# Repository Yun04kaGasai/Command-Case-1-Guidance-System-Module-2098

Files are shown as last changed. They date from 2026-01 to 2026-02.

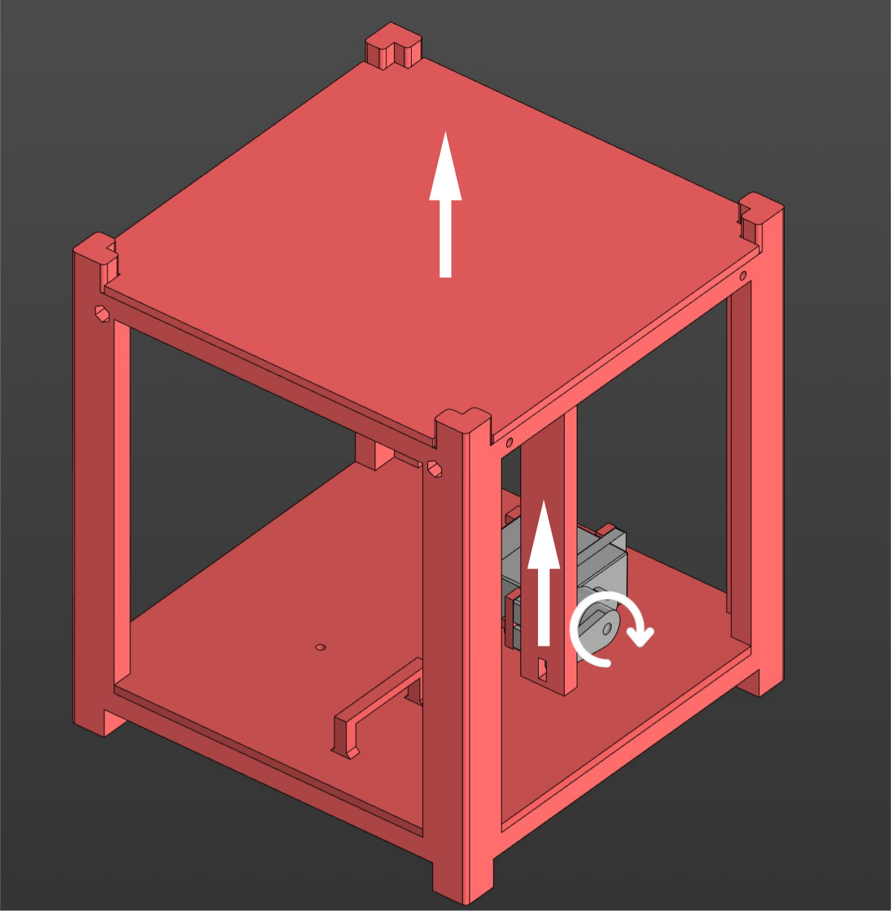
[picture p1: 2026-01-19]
Assets/Kinematicheskaya skhema 2.png

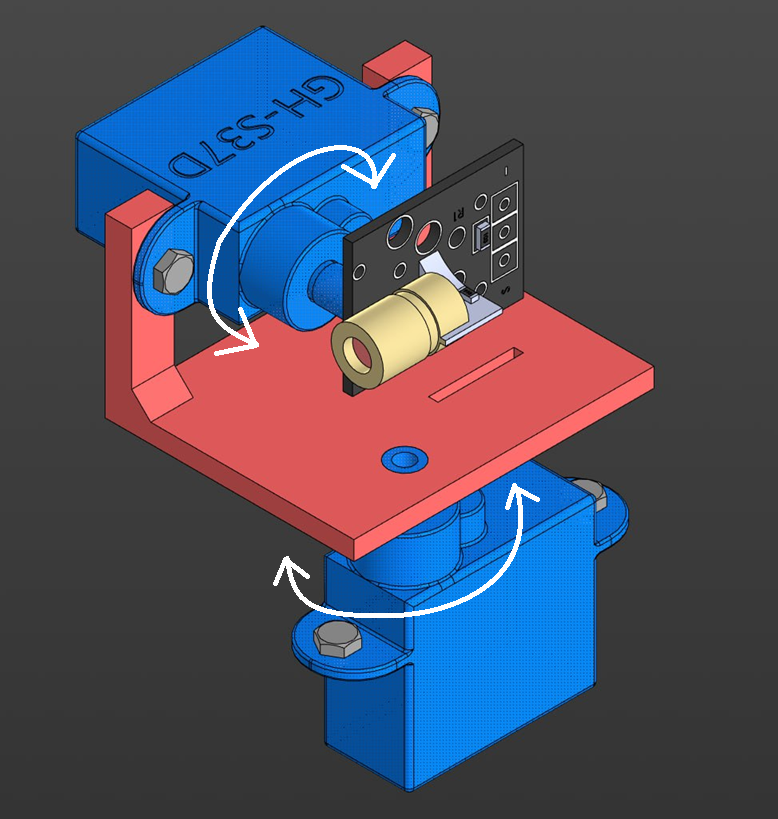
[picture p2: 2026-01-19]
Assets/Kinematicheskaya skhema 1.png

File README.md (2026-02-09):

# Описание модуля
isometry isometry razn

## Модуль обеспечивает:
- Двухосевое наведение лазерного луча (±40° по каждой оси с шагом 10°), исходящего из геометрического центра корпуса CubeSat 1U;
- Приём управляющих команд по радиоканалу (nRF24L01);
- Последовательное выполнение четырёх тестовых сканирующих режимов: горизонтального, вертикального и двух диагональных;
- Автономную работу исполнительной части сразу после включения питания;
- Отправку телеметрической информации — включая уникальный ID устройства, текущие углы наведения и номер активного режима.
## Аппаратная часть включает:
- STM32 Blue Pill — главный контроллер (наземная станция), принимающий команду START от ПК и передающий последовательности позиций по радио;
- Raspberry Pi Pico (RP2040) — исполнительный модуль внутри CubeSat, управляющий двумя сервоприводами GH-S37A и лазером KY-008;
- Радиомодуль nRF24L01 для односторонней связи от STM32 к RP2040;
- Собственный 3D-напечатанный корпус, соответствующий стандарту CubeSat 1U, с учётом размещения лазера в геометрическом центре.
### Проект полностью реализован участниками: от проектирования механики и электронной схемы до разработки прошивки обеих микроконтроллеров и сборки макета.

# Руководители
- Пивоварова Наталья Викторовна
- Гоптарь Евгений Андреевич
# Участники команды:
- Хачатрян Карен 11Г Школа №2098
- Козадаев Егор 11Г Школа №2098
- Зотова София 11Г Школа №2098
- Лукашев Николай 11Г Школа №2098
# Этапы производства
- Проектирование:
    - Создание алгоритма
    - Создание 3д моделей и параллельная разработка электронной схемы
- Создание документации и параллельное прототипирование
- Сборка и написание кода
- Испытание (Финал)
## Цель такова:
#### Реализовать решение задания по созданию спутника формата Cubesat 1U, сделав ему оптимальную компановку и разработав корпус с надёжным креплением, который будет укладываться в размерные стандарты таковых.

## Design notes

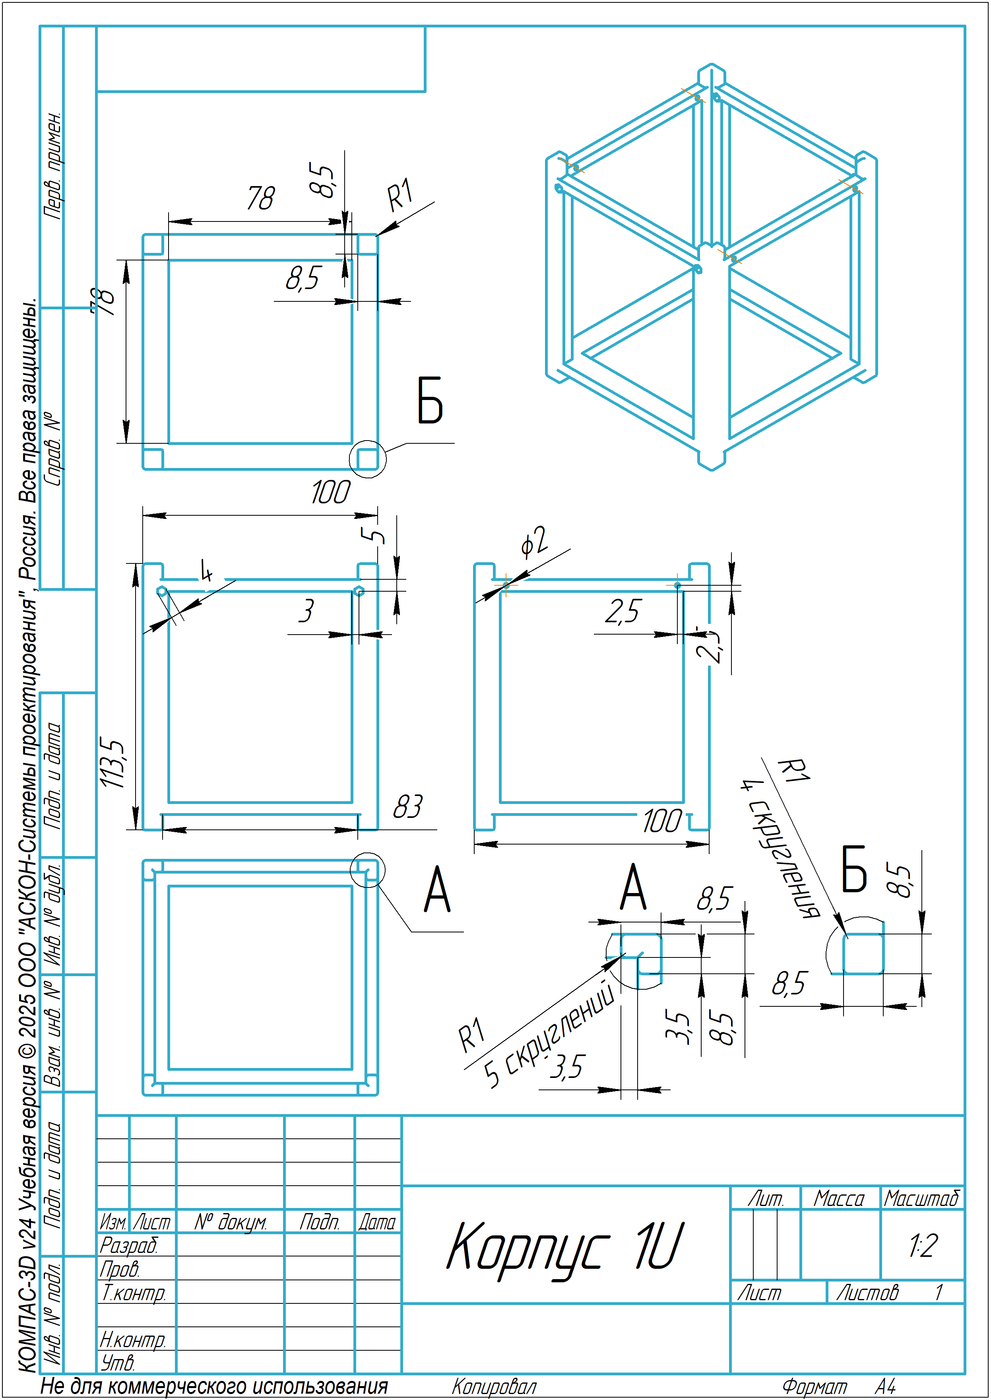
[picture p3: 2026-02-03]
Assets/Чертежи/Корпус 1U.png

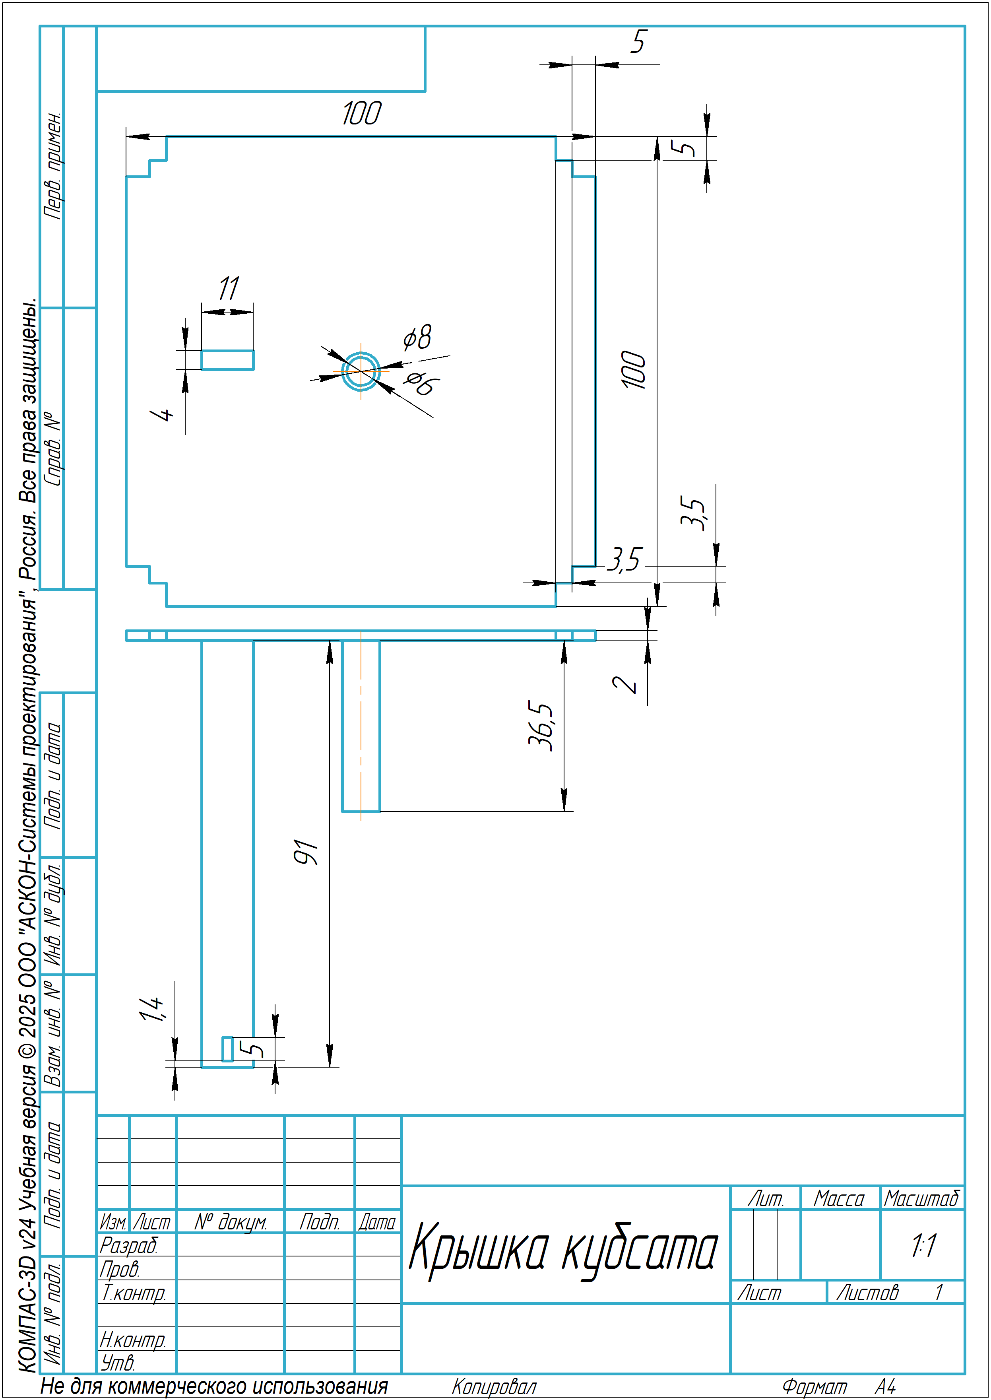
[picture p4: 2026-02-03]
Assets/Чертежи/Крышка кубсата.png

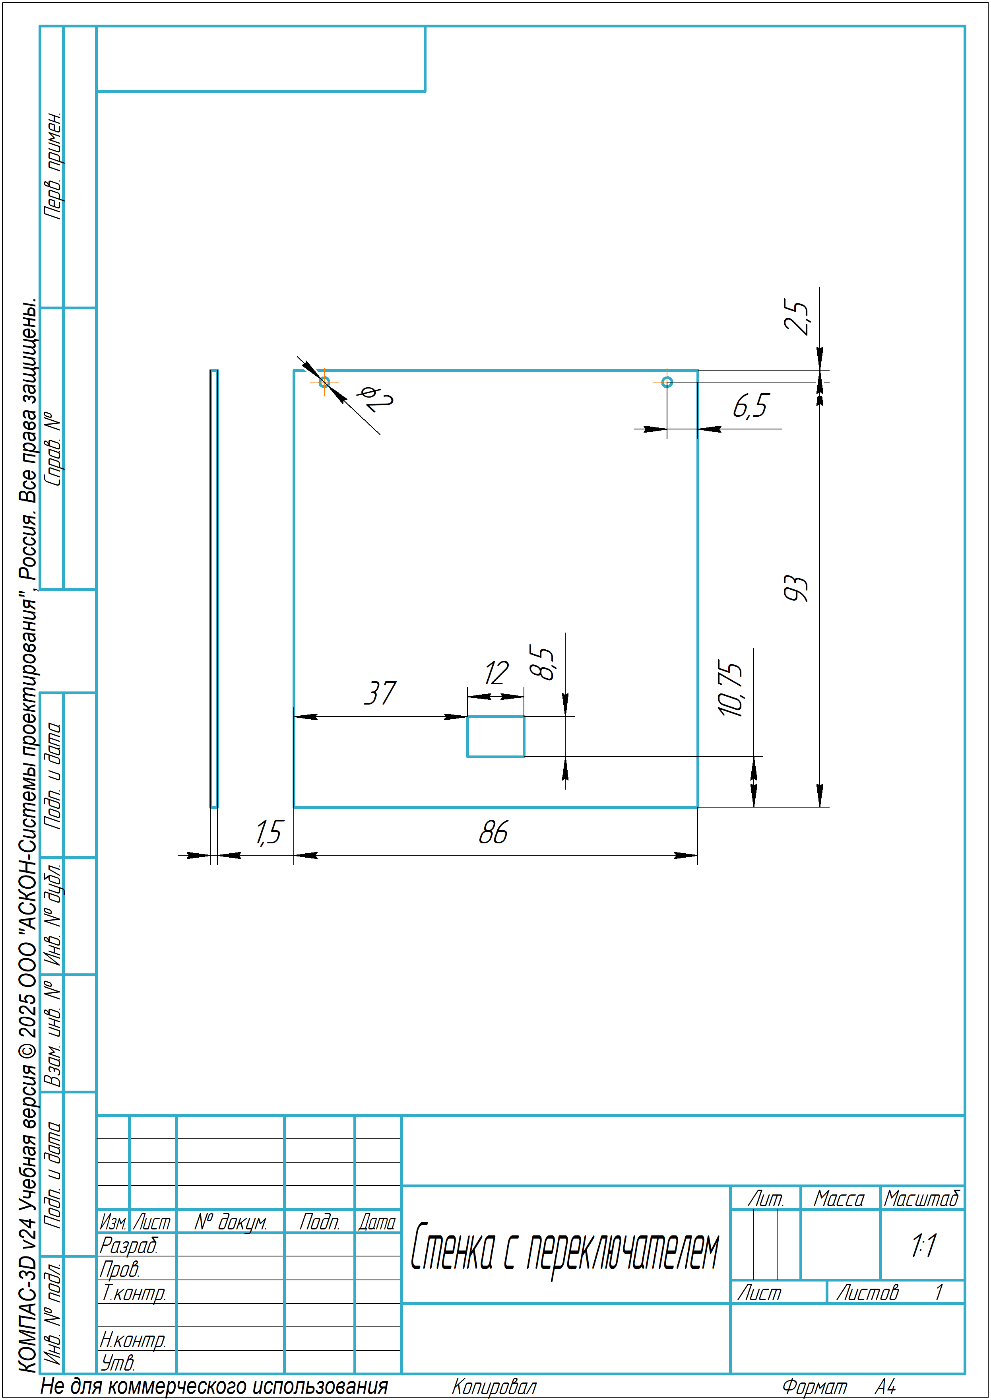
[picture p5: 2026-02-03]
Assets/Чертежи/Стенка с переключателем.png

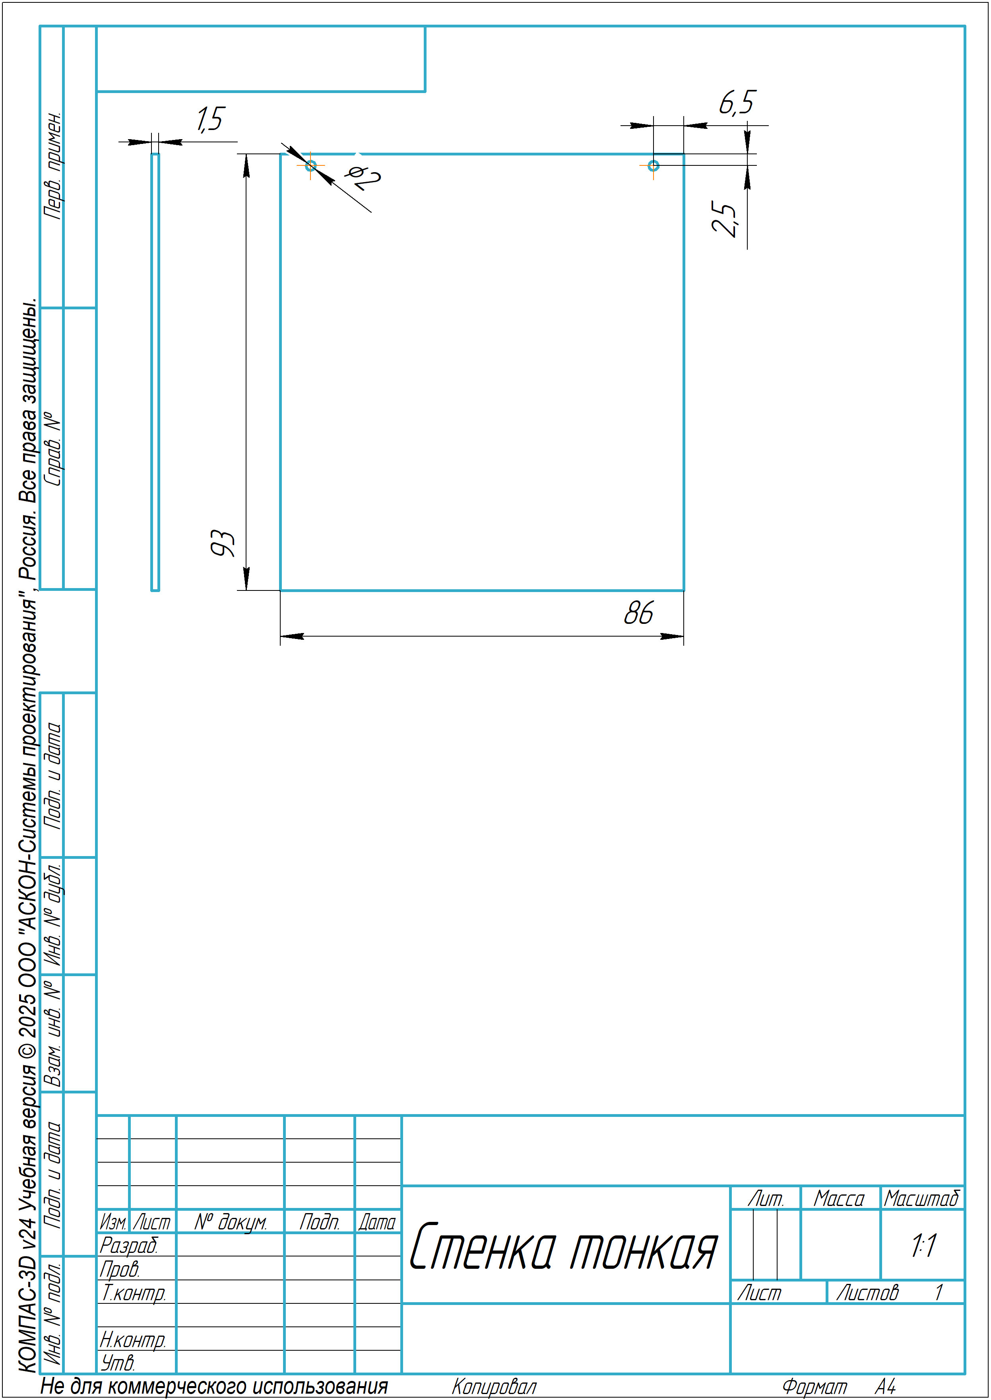
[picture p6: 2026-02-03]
Assets/Чертежи/Стенка тонкая.png

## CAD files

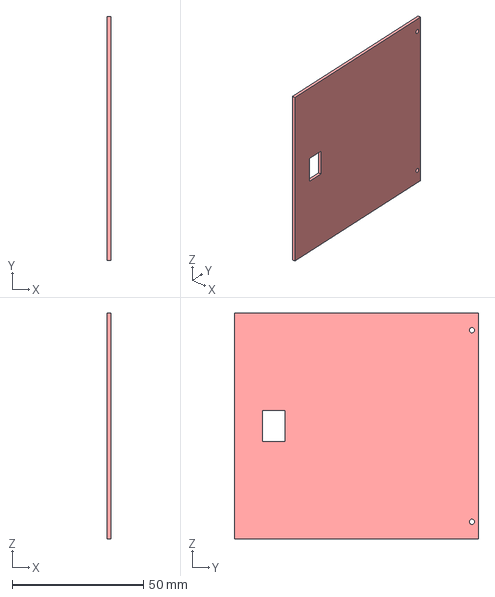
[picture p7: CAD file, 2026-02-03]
3D-модели/Стенка с переключателем.stp
1.50 x 93.0 x 86.0 mm

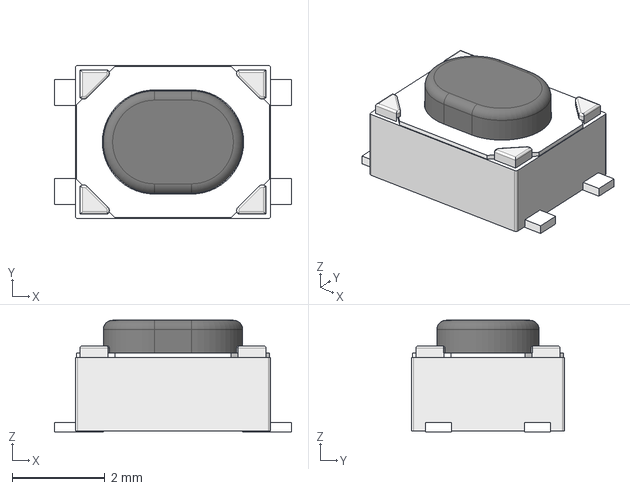
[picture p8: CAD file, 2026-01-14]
Assets/Сборка/RP2040/KLS7-TS3401_B.stp
5.10 x 3.30 x 2.40 mm

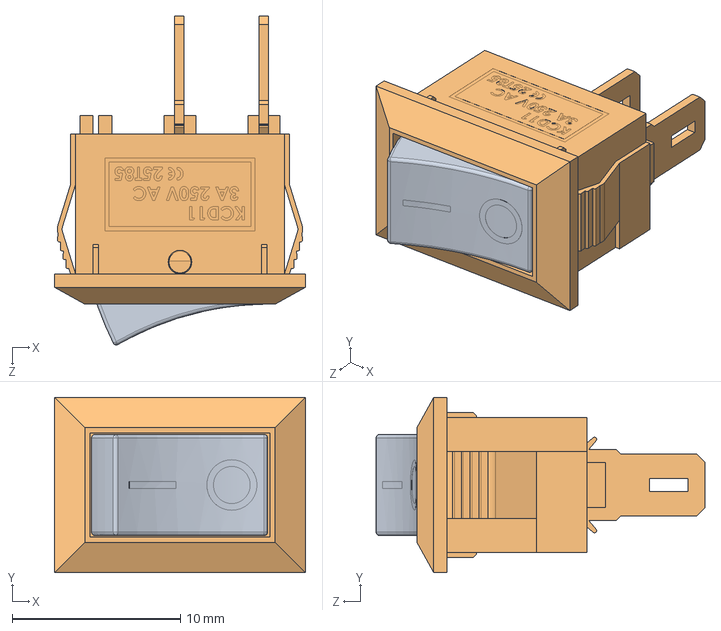
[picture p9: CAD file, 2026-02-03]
Assets/Сборка/Switch_KCD11.STEP
14.9 x 10.4 x 19.5 mm

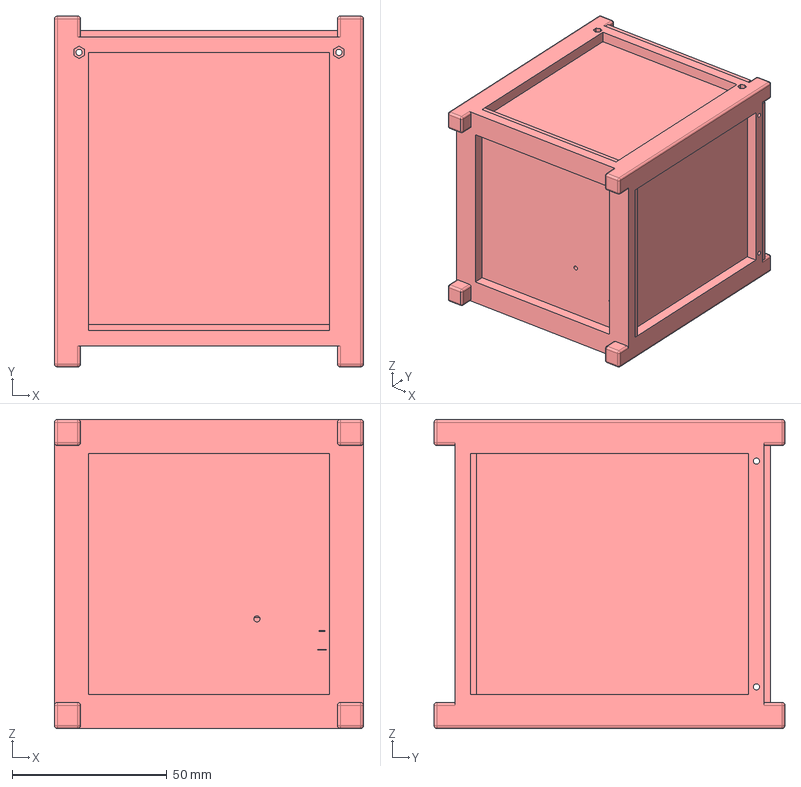
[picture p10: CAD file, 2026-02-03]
3D-модели/Сборка Кубсат.stp
100.0 x 113.5 x 100.0 mm
Gh-S37D Servo x 2
KY-008
AMS1117Pin
Text x 2
AMS1117Body x 2
AMS117Pin
LEDS_3
C-Type Female - 6-Pin SMD
0603 Chip SMD LED (1.6x0.8mm) x 4
Nrf24L01
MG90S
arm

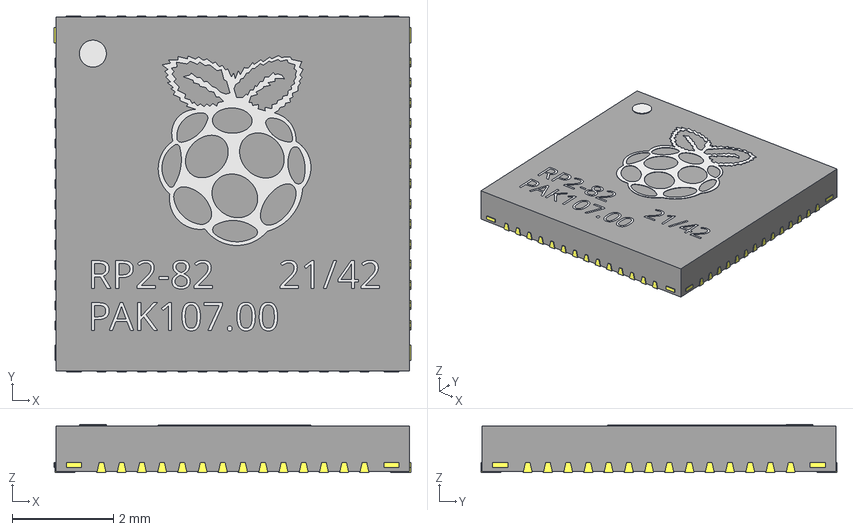
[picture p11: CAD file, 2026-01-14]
Assets/Сборка/RP2040/IC_RP2040.step
7.05 x 7.04 x 0.95 mm
Metal
Pin001
Pin002
Pin003
Pin004
Pin005
Pin006
Pin007
Pin008
Pin009
Pin010
Pin011
Pin012
Pin013
Pin014
Pin015
Pin016
Pin017
Pin018
Pin019
Pin020
Pin021
Pin022
Pin023
Pin024
Pin025
Pin026
Pin027
Pin028
Pin029
Pin030
Pin031
Pin032
Pin033
Pin034
Pin035
Pin036
Pin037
Pin038
Pin039
Pin040
Pin041
Pin042
Pin043
Pin044
Pin045
Pin046
Pin047
Pin048
Pin049
Pin050
Pin051
Pin052
Pin053
Pin054
Pin055
Pin056
ShapeString003
ShapeString002
ShapeString001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

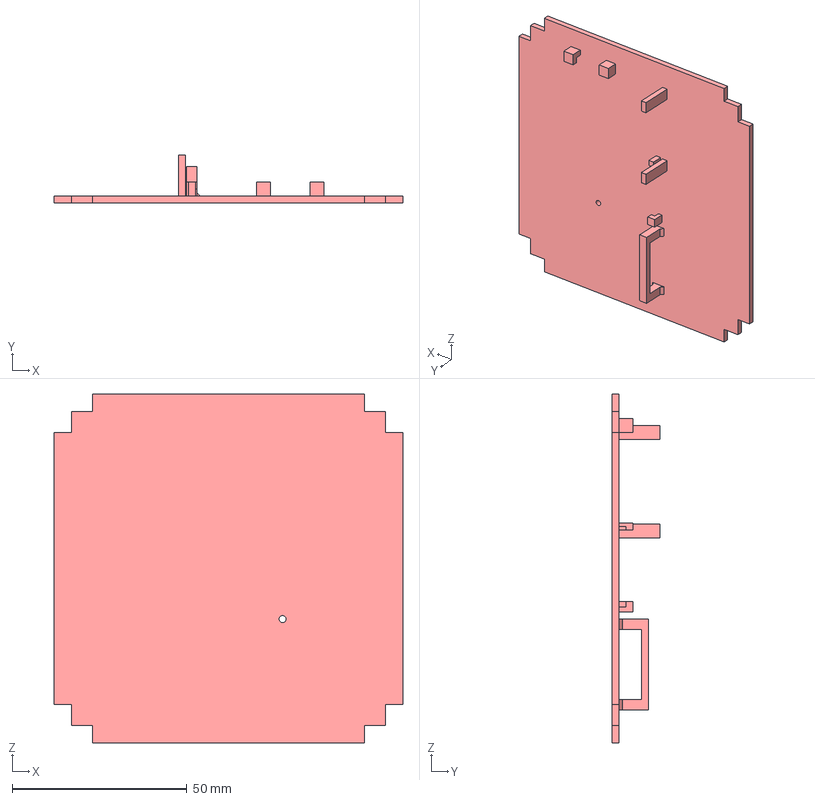
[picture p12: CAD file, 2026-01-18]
Assets/Сборка/Дно.stp
100.0 x 13.8 x 100.0 mm

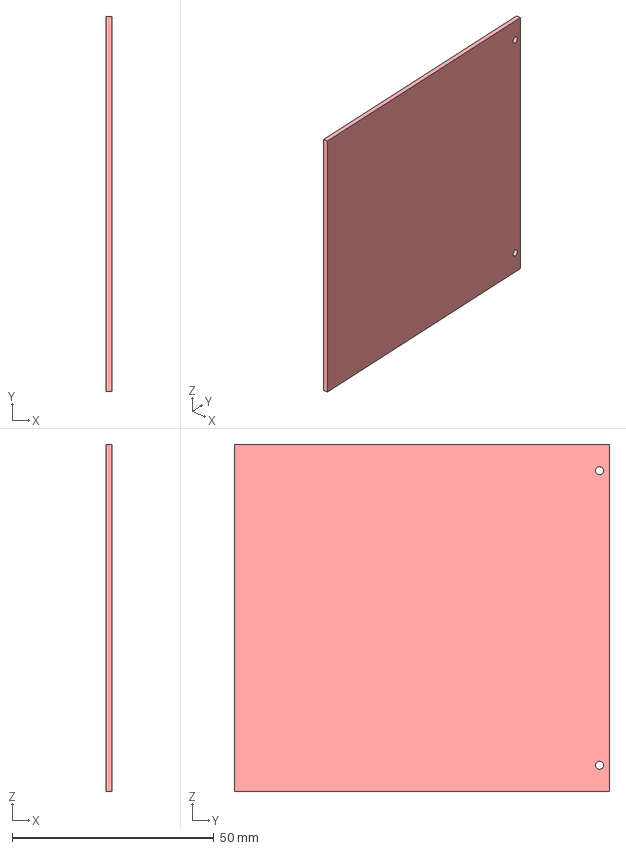
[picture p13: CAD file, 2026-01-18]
3D-модели/Стенка малая.stp
1.50 x 93.0 x 86.0 mm

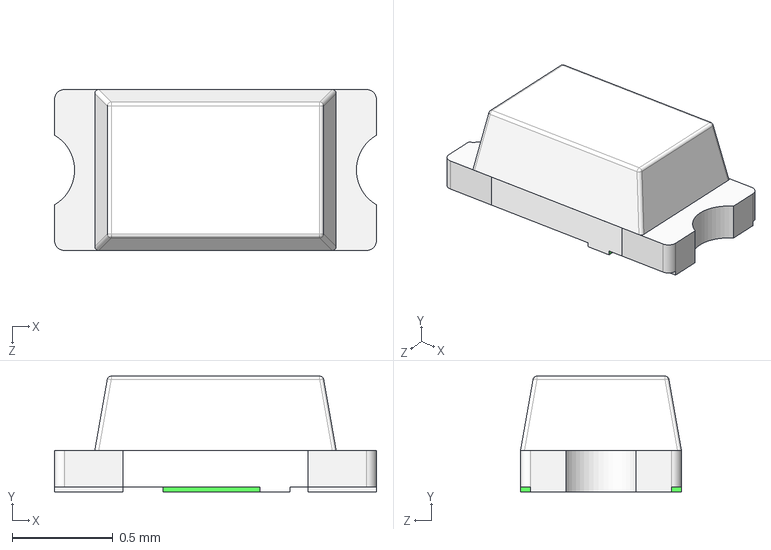
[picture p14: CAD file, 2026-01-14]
Assets/Сборка/RP2040/0603 Chip SMD LED (1.6x0.8mm).STEP
1.60 x 0.575 x 0.8 mm

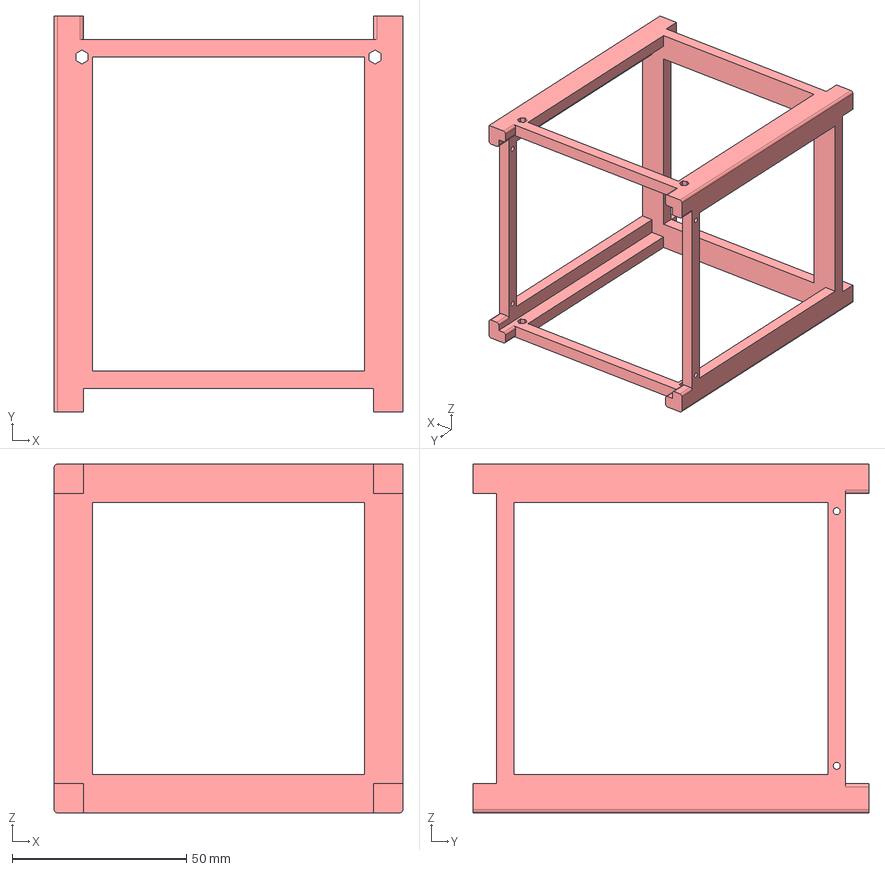
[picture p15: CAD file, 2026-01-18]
Assets/Сборка/Корпус.stp
100.0 x 113.5 x 100.0 mm

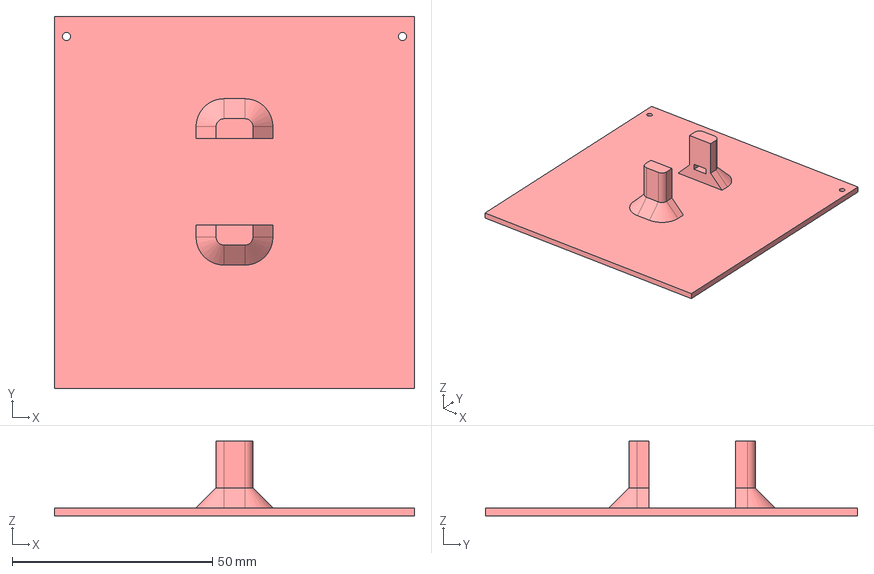
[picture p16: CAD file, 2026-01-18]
3D-модели/Стенка_С_Креплением.stp
90.0 x 93.0 x 18.7 mm

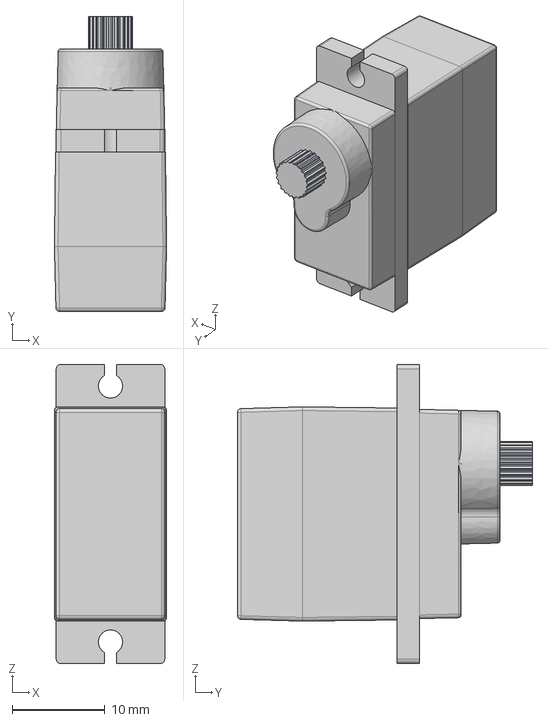
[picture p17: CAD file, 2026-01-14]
Assets/Сборка/MG90S TEETH.step
12.1 x 31.8 x 32.2 mm

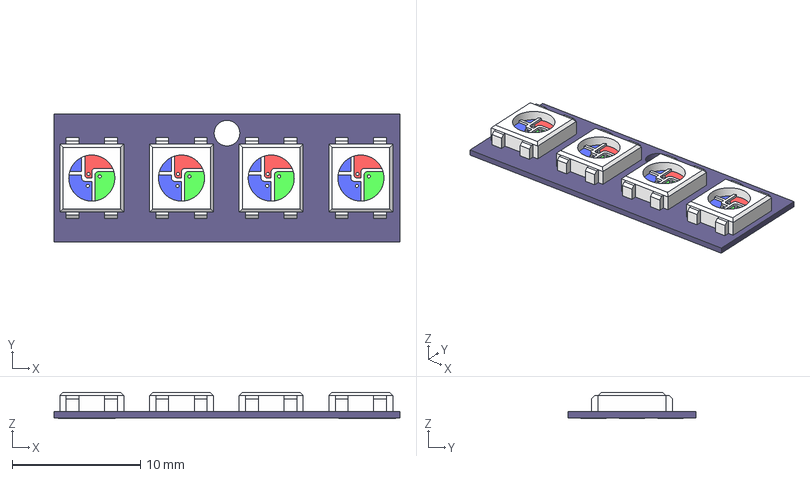
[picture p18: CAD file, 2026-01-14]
Assets/Сборка/RP2040/WS2812-4 ICQMCU.step
27.0 x 10.0 x 2.05 mm
Sketch
PCB
LEDS
Solder strips

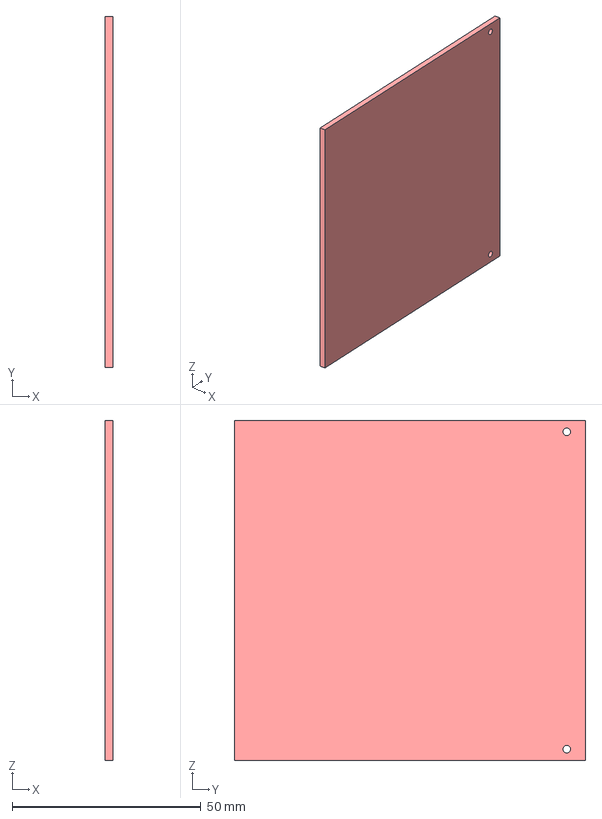
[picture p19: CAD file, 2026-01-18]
3D-модели/Стенка большая.stp
2.00 x 93.0 x 90.0 mm

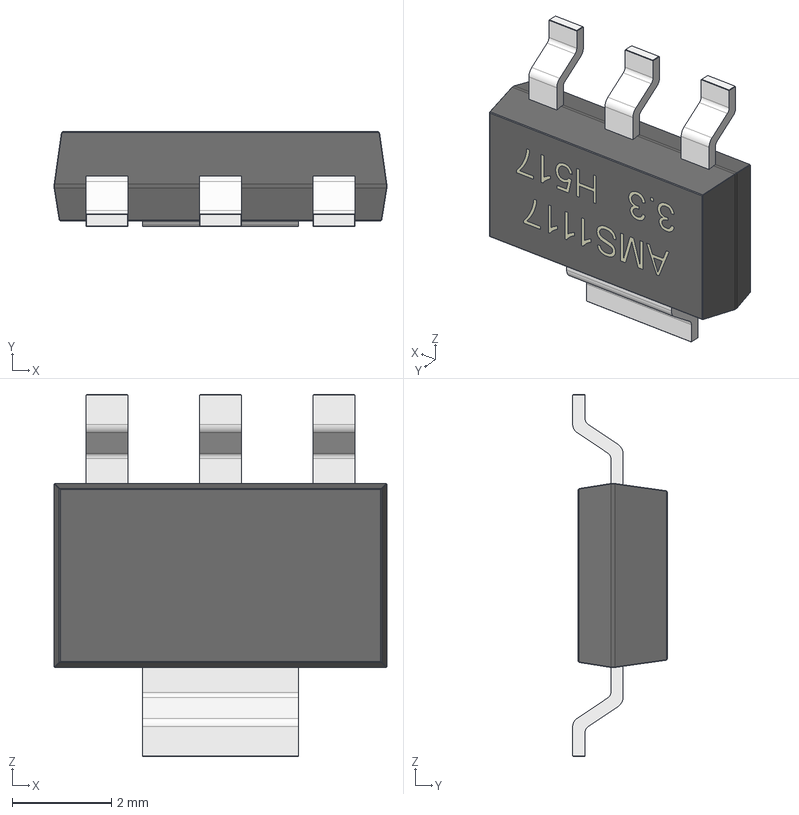
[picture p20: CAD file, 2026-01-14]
Assets/Сборка/AMS1117_3V3_axisY.step
6.71 x 1.91 x 7.30 mm

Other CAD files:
Assets/Сборка/RP2040/Rp2040 Type C.stl
Assets/Сборка/RadioFrequencyCommunicationModule_nRF24L01.STEP
Assets/Сборка/RP2040/C-Type Female - 6-Pin SMD.step
3D-модели/Корпус.stp
3D-модели/Крепление сервопривода.stp
3D-модели/Крышка.stp
Assets/Сборка/DC_Power_Jack_PCB_Mounted_2.1mm.step
Assets/Сборка/MG90S ARM.step
Assets/Сборка/Сборка Кубсат.stp

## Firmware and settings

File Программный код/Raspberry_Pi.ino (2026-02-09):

#include <SPI.h>
#include <nRF24L01.h>
#include <RF24.h>
#include <Servo.h>

#define SERVO_AZIM   6
#define SERVO_TILT   7
#define SERVO_COVER  8
#define LASER_PIN    5
#define CE_PIN       14
#define CSN_PIN      15

RF24 radio(CE_PIN, CSN_PIN);
Servo servoAzim, servoTilt, servoCover;
const byte address[6] = "CMD01";

int angleToServo(int8_t angle) {
  return 90 + angle;
}

void runScans() {
  static bool coverOpened = false;
  if (!coverOpened) {
    servoCover.write(90);
    coverOpened = true;
  }

  digitalWrite(LASER_PIN, HIGH);

  for (int a = -40; a <= 40; a += 10) {
    servoAzim.write(angleToServo(a));
    servoTilt.write(angleToServo(0));
    delay(3000);
  }

  for (int t = -40; t <= 40; t += 10) {
    servoAzim.write(angleToServo(0));
    servoTilt.write(angleToServo(t));
    delay(3000);
  }

  for (int i = -40; i <= 40; i += 10) {
    servoAzim.write(angleToServo(i));
    servoTilt.write(angleToServo(i));
    delay(3000);
  }

  for (int i = -40; i <= 40; i += 10) {
    servoAzim.write(angleToServo(i));
    servoTilt.write(angleToServo(-i));
    delay(3000);
  }

  digitalWrite(LASER_PIN, LOW);
  servoAzim.write(90);
  servoTilt.write(90);
}

void setup() {
  pinMode(LASER_PIN, OUTPUT);
  digitalWrite(LASER_PIN, LOW);

  servoAzim.attach(SERVO_AZIM);
  servoTilt.attach(SERVO_TILT);
  servoCover.attach(SERVO_COVER);

  servoCover.write(0);
  servoAzim.write(90);
  servoTilt.write(90);

  SPI.begin();
  radio.begin();
  radio.setPALevel(RF24_PA_MIN);
  radio.setDataRate(RF24_1MBPS);
  radio.openReadingPipe(0, address);
  radio.startListening();

  Serial.begin(115200);
}

void loop() {
  if (radio.available()) {
    char cmd[6] = {0};
    radio.read(cmd, sizeof(cmd));
    if (strncmp(cmd, "START", 5) == 0) {
      Serial.println("RECEIVED");
      runScans();
    }
  }
  delay(10);
}

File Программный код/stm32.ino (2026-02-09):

#include <SPI.h>
#include <nRF24L01.h>
#include <RF24.h>

#define CE_PIN  PA0
#define CSN_PIN PA1

RF24 radio(CE_PIN, CSN_PIN);
const byte address[6] = "CMD01";

void setup() {
  pinMode(PC13, OUTPUT);
  Serial.begin(115200);

  SPI.setMOSI(PA7);
  SPI.setMISO(PA6);
  SPI.setSCLK(PA5);
  SPI.begin();

  radio.begin();
  radio.setPALevel(RF24_PA_MIN);
  radio.setDataRate(RF24_1MBPS);
  radio.openWritingPipe(address);
  radio.stopListening();

  digitalWrite(PC13, LOW);
}

void loop() {
  if (Serial.available()) {
    String input = Serial.readStringUntil('\n');
    input.trim();
    if (input == "START") {
      const char cmd[] = "START";
      bool ok = radio.write(cmd, sizeof(cmd));
      if (ok) {
        Serial.println("SENT");
      } else {
        Serial.println("FAIL");
      }
    }
  }
  delay(10);
}

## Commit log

2025-12-23 Добавил 3д модели
    Сборки в .step
    [22.12.stp]
2025-12-25 Серво
2025-12-25 Обновил
2025-12-25 Add files via upload
    Блок - схема работы системы: наземная станция - CubSat
2025-12-25 Отчетная документация
2026-01-14 Update
    Подготовка к объединению веток
    [22.12.stl, 22.12.stp, Крышка Кубсата.3mf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]
2026-01-14 Added Code
    Первая версия прошивки
    используется Ардуино Нано в качестве наземной станции и Расберри Пай Пико в качестве контроллера на самом спутнике, здесь задействован только один сервопривод, что в дальнейшем будет исправлено
    [Raspberry_Pi.ino]
2026-01-16 Code v2
    Добавлен код для платы STM32 , он пришёл на замену Arduino Nano, сделали багфиксы и отредактировали модели (цвет ещё не изменён, но вскоре будет изменён на цвет реального прототипа)
2026-01-16 Обновил расположение всего
2026-01-18 Обновил 3д модели
    [Дно.stp, Корпус.stp, Крепление сервопривода.stp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]
2026-01-19 Sync of some stuff
    Добавились чертежи и итоговый вид деталей был приведён в порядок
2026-01-19 Upd
    все чертежи, кроме кинематических схем
2026-01-27 БАНАНЫЫЫЫЫЫЫЫ
2026-01-27 СЛИВЫЫЫ
2026-02-03 Обновление кода
2026-02-03 обновление модели сборки
    [Сборка Кубсат.stp]
2026-02-03 Revert "Delete Сборка Кубсат.a3d"
    This reverts commit 37a074db713237b272782622914ebbd9de2b50d8.
2026-02-03 Reapply "Delete Сборка Кубсат.a3d"
    This reverts commit f6463e73277044ab87a9bc5917f28c5507789eed.
2026-02-09 Обновил Код
